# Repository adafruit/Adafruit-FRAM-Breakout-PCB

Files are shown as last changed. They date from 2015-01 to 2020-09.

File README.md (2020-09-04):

# Adafruit FRAM Breakout PCBs

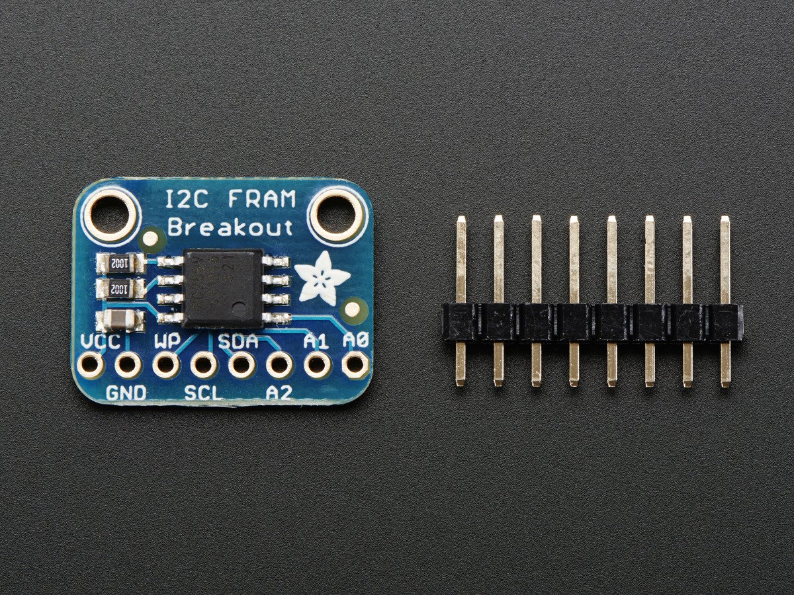
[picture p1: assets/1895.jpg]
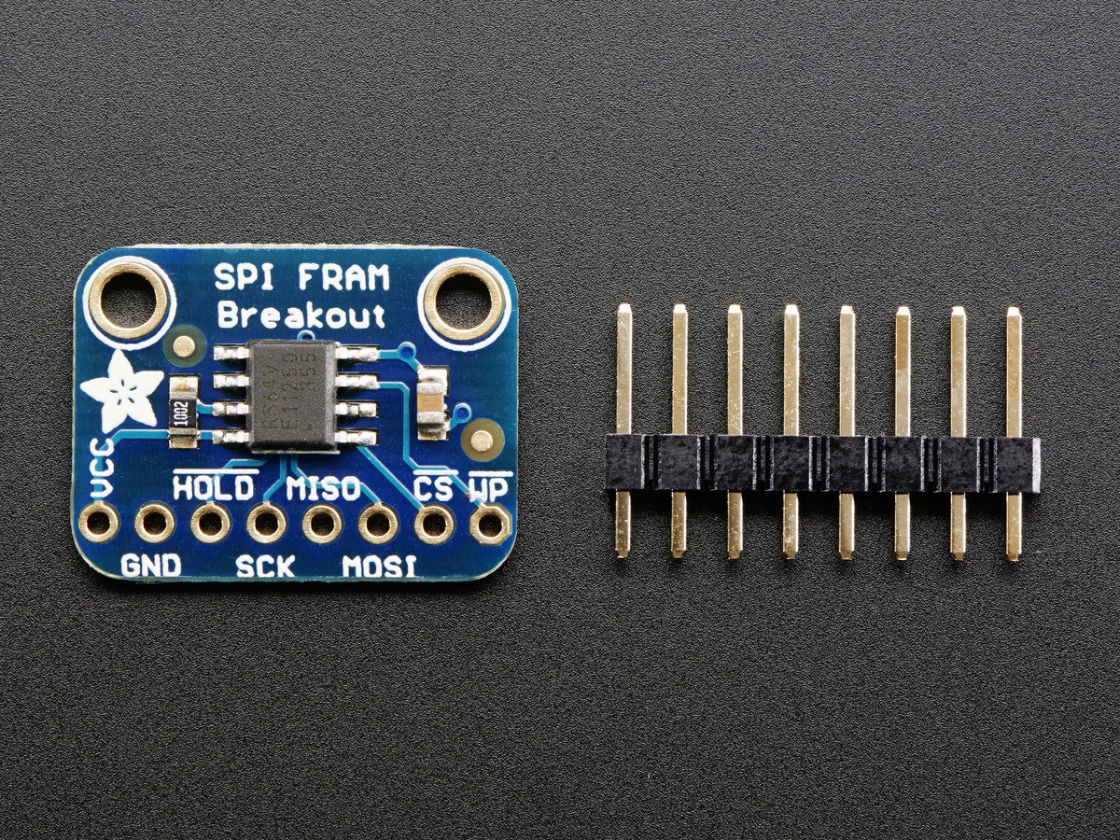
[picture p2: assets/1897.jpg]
&nbsp; <br />
Click to purchase from the Adafruit Shop:
- [I2C Version](https://www.adafruit.com/product/1895)
- [SPI Version](https://www.adafruit.com/product/1897)
- [2 Mbit SPI Version](https://www.adafruit.com/product/4718)
- [4 Mbit SPI Version](https://www.adafruit.com/product/4719)

FRAM, or Ferroelectric Ram, is pretty cool! It's similar to Dynamic random-access memory, only with a ferroelectric layer instead of a dielectric layer. This gives it stable handling (the bytes you write are non-volatile) with dynamic responsiveness (you can write them very fast!)

Now, with our FRAM breakout boards, you can add some FRAM storage to your next DIY project. FRAM allows for a lower power usage and a faster write performance. It's excellent for low-power or inconsistent-power datalogging or data buffering where you want to stream data fast while also keeping the data when there's no power. Unlike Flash or EEPROM there's no pages to worry about. Each byte can be read/written 10,000,000,000,000 times so you don't have to worry too much about wear leveling.

These particular FRAM chips have 64 Kbits (8 KBytes) of storage, interfaces using SPI or I2C (select the correct board for the correct bus, they cannot do both!), and can run at up to 20MHz SPI clock rates. Each byte can be read and written instantaneously (like SRAM) but will keep the memory for 95 years at room temperature.

PCB files for Adafruit I2C &amp; SPI FRAM Breakout Boards. 
Format is EagleCAD schematic and board layout

For more details, check out the product pages at

-----> https://www.adafruit.com/products/1895

-----> https://www.adafruit.com/products/1897

### License

Adafruit invests time and resources providing this open source design, please support Adafruit and open-source hardware by purchasing products from [Adafruit](https://www.adafruit.com)!

All text above must be included in any redistribution

Designed by Limor Fried/Ladyada for Adafruit Industries.
Creative Commons Attribution/Share-Alike, all text above must be included in any redistribution. 
See license.txt for additional information.

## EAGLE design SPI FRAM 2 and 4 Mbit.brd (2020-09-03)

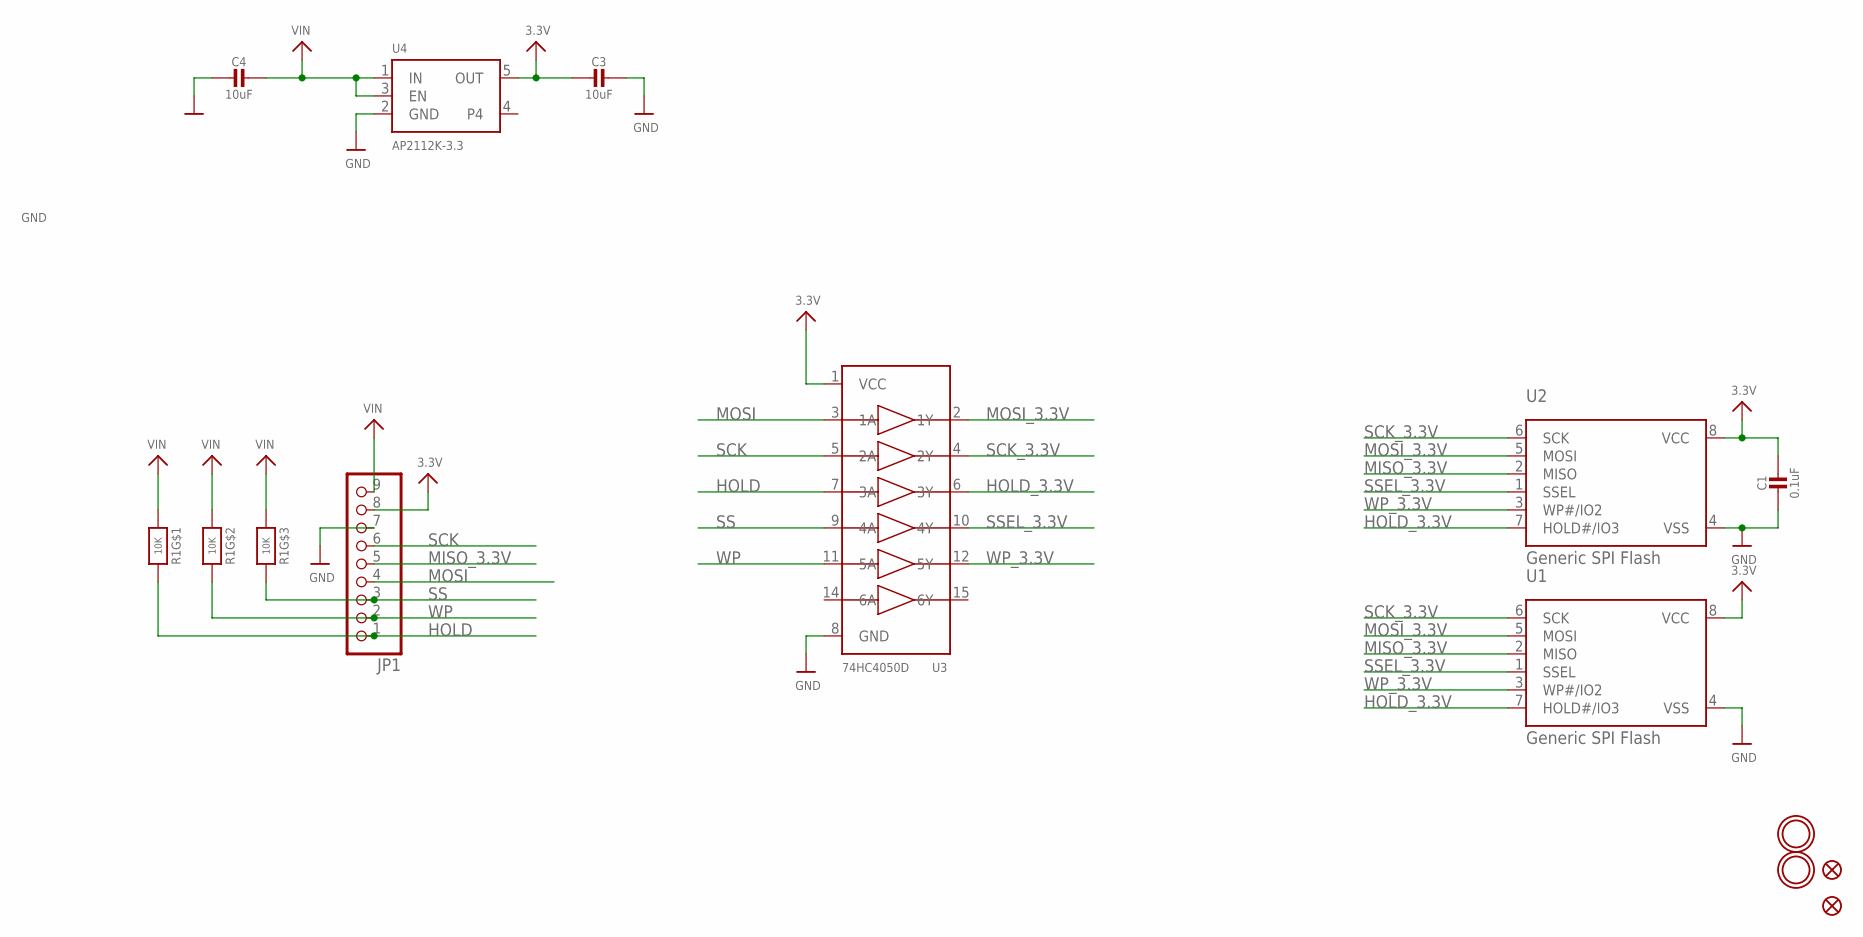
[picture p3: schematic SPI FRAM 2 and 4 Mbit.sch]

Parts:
C1: 0.1uF; 0603-NO
C3, C4: 10uF; 0805-NO
FID2, FID3: FIDUCIAL_1MM
JP1: HEADER-1X970MIL; 1X09_ROUND_70
R1: 10K; RESPACK_4X0603
U1: Generic SPI Flash; SOIC8_208MIL
U2: Generic SPI Flash; USON8
U3: 74HC4050D; TSSOP16
U4: AP2112K-3.3; SOT23-5
U$16, U$17: MOUNTINGHOLE2.5; MOUNTINGHOLE_2.5_PLATED

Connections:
3.3V: C1.1, C3.2, JP1.8, U1.8 (VCC), U2.8 (VCC), U3.1 (VCC), U4.5 (OUT)
GND: C1.2, C3.1, C4.2, JP1.7, U1.4 (VSS), U2.4 (VSS), U3.8 (GND), U4.2 (GND)
HOLD: JP1.1, R1.8 (2), U3.7 (3A)
HOLD_3.3V: U1.7 (HOLD#/IO3), U2.7 (HOLD#/IO3), U3.6 (3Y)
MISO_3.3V: JP1.5, U1.2 (MISO), U2.2 (MISO)
MOSI: JP1.4, U3.3 (1A)
MOSI_3.3V: U1.5 (MOSI), U2.5 (MOSI), U3.2 (1Y)
SCK: JP1.6, U3.5 (2A)
SCK_3.3V: U1.6 (SCK), U2.6 (SCK), U3.4 (2Y)
SS: JP1.3, R1.6 (2), U3.9 (4A)
SSEL_3.3V: U1.1 (SSEL), U2.1 (SSEL), U3.10 (4Y)
VIN: C4.1, JP1.9, R1.1, R1.2 (1), R1.3 (1), U4.1 (IN), U4.3 (EN)
WP: JP1.2, R1.7 (2), U3.11 (5A)
WP_3.3V: U1.3 (WP#/IO2), U2.3 (WP#/IO2), U3.12 (5Y)

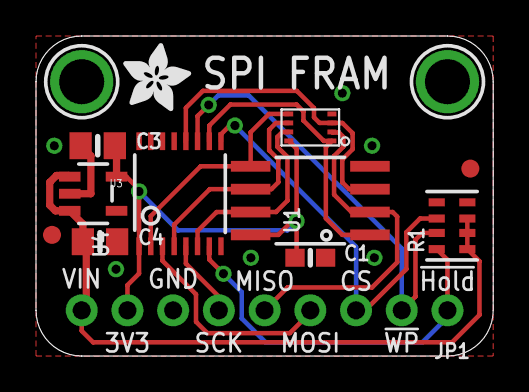
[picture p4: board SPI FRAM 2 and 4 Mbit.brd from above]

Board: 2 copper layers, 25.4 x 17.8 mm, 15 parts (1 on the bottom side), 14 nets.

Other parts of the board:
U$19: ADAFRUIT_3.5MM
U$21: PCBFEAT-REV-040

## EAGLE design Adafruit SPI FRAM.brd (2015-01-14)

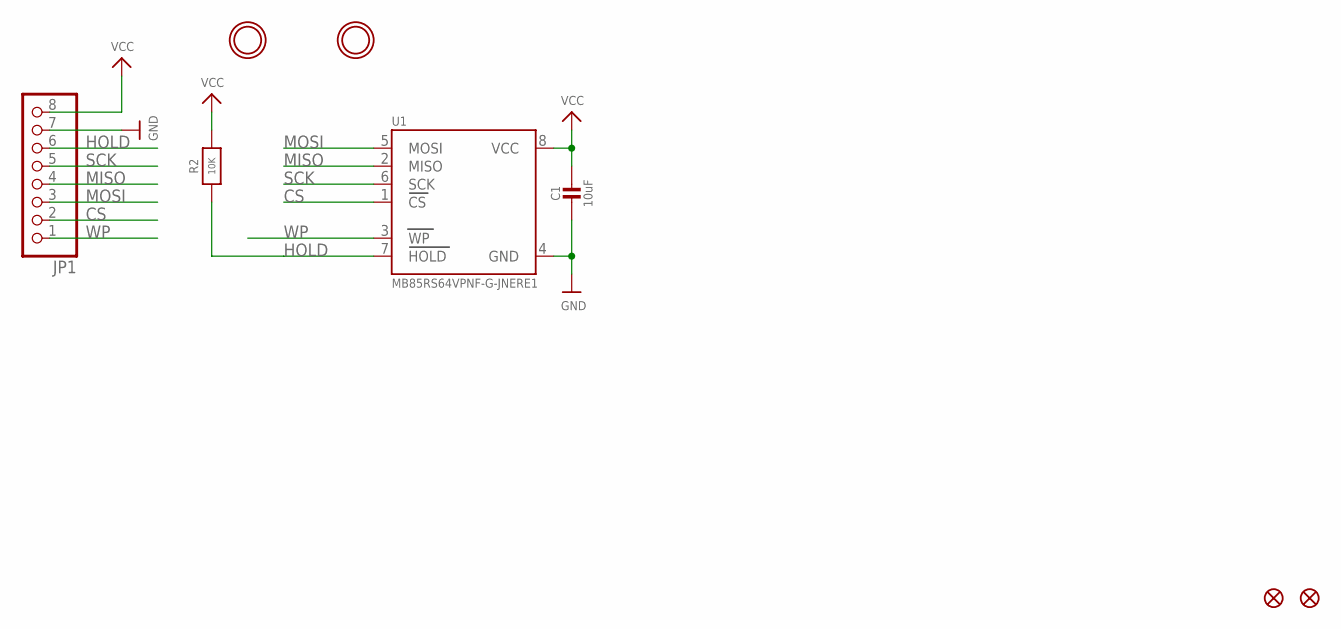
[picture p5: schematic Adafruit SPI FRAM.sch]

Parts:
C1: 10uF; _0805MP
FID1, FID2: FIDUCIAL""; FIDUCIAL_1MM
JP1: HEADER-1X870MIL; 1X08_ROUND_70
R2: 10K; _0805MP
U1: MB85RS64VPNF-G-JNERE1; SOIC8_150MIL
U$5, U$6: MOUNTINGHOLE2.5; MOUNTINGHOLE_2.5_PLATED

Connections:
CS: JP1.2, U1.1 (CS)
GND: C1.2, JP1.7, U1.4 (GND)
HOLD: JP1.6, R2.1, U1.7 (HOLD)
MISO: JP1.4, U1.2 (MISO)
MOSI: JP1.3, U1.5 (MOSI)
SCK: JP1.5, U1.6 (SCK)
VCC: C1.1, JP1.8, R2.2, U1.8 (VCC)
WP: JP1.1, U1.3 (WP)

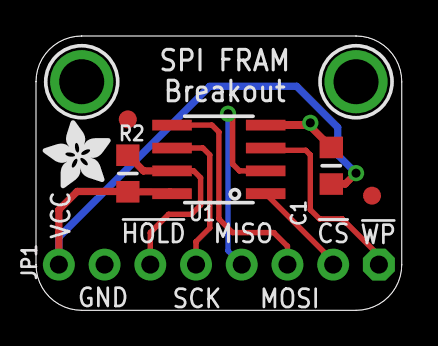
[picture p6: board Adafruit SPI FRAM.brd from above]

Board: 2 copper layers, 20.3 x 15.2 mm, 10 parts (1 on the bottom side), 8 nets.

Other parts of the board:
U$4, U$7: ADAFRUIT_3.5MM

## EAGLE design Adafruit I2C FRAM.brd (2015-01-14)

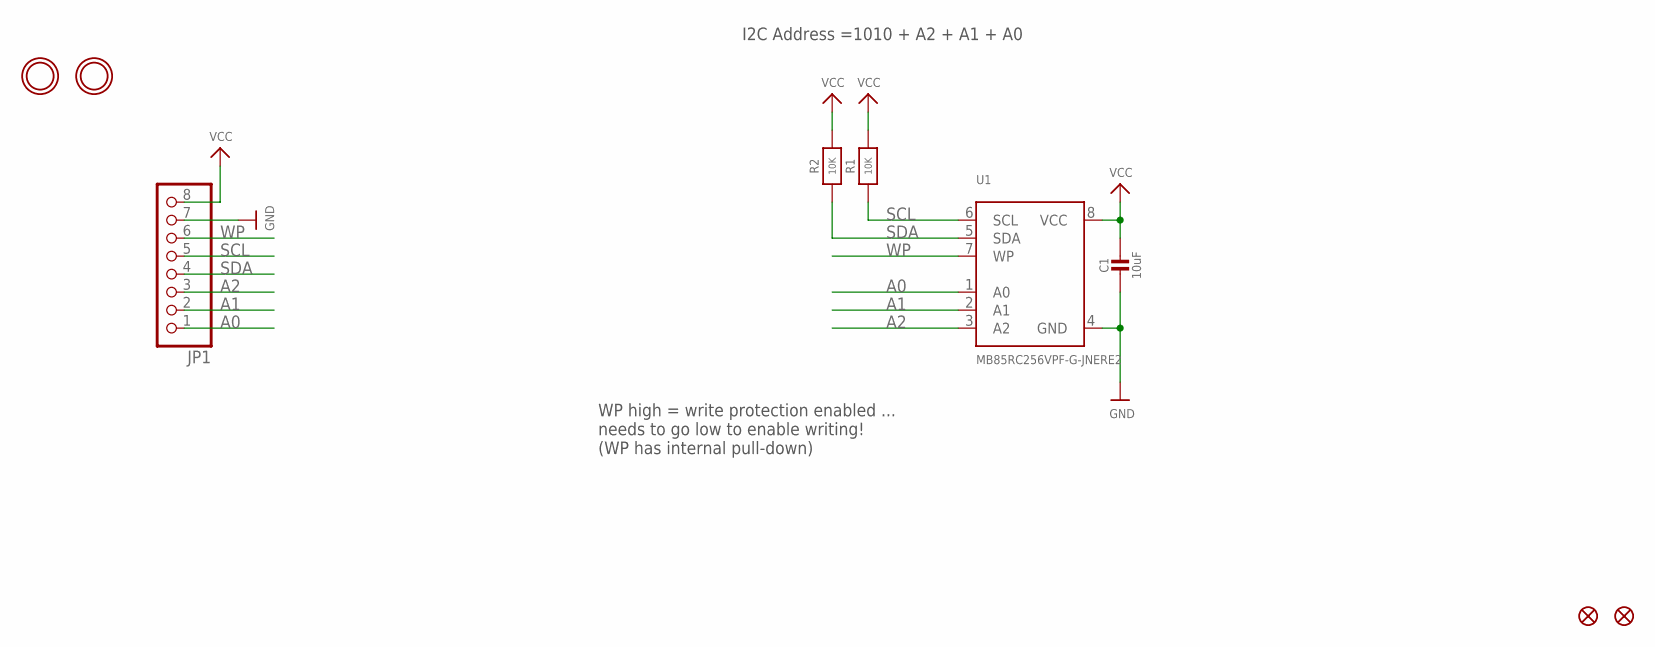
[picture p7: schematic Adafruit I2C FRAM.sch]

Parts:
C1: 10uF; _0805MP
FID1, FID2: FIDUCIAL""; FIDUCIAL_1MM
JP1: HEADER-1X870MIL; 1X08_ROUND_70
R1, R2: 10K; _0805MP
U1: MB85RC256VPF-G-JNERE2; SOIC8_208MIL
U$5, U$6: MOUNTINGHOLE2.5; MOUNTINGHOLE_2.5_PLATED

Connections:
A0: JP1.1, U1.1 (A0)
A1: JP1.2, U1.2 (A1)
A2: JP1.3, U1.3 (A2)
GND: C1.2, JP1.7, U1.4 (GND)
SCL: JP1.5, R1.1, U1.6 (SCL)
SDA: JP1.4, R2.1, U1.5 (SDA)
VCC: C1.1, JP1.8, R1.2, R2.2, U1.8 (VCC)
WP: JP1.6, U1.7 (WP)

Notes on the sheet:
WP high = write protection enabled ... needs to go low to enable writing! (WP has internal pull-down)
I2C Address =1010 + A2 + A1 + A0

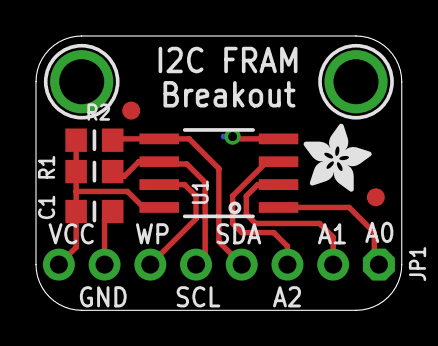
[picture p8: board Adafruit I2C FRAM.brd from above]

Board: 2 copper layers, 20.3 x 15.2 mm, 10 parts (0 on the bottom side), 8 nets.

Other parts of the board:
U$4: ADAFRUIT_3.5MM

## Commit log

2015-01-14 save a repo - double up!
    [Adafruit I2C FRAM.brd, Adafruit I2C FRAM.sch, Adafruit SPI FRAM.brd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]
2020-09-03 Added files for pid 4718
    [SPI FRAM Rev C.brd, SPI FRAM Rev C.sch]
2020-09-04 Renamed files for 4718 and 4719, added them to README
    [SPI FRAM 2 and 4 Mbit.brd, SPI FRAM 2 and 4 Mbit.sch]

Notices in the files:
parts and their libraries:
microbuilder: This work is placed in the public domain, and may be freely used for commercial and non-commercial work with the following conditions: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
